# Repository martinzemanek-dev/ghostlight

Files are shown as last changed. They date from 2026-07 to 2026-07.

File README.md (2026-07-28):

# Ghostlight
Small board under a see-through miniature, to light it up. The board is powered by a battery and the light is programmable.
## Power supply
Circuit is expected to be build for 3V
### Battery
CR2032 for start. It needs holder at the bottom [BAT-HLD-001](https://cz.mouser.com/ProductDetail/712-BAT-HLD-001)
### Miscelenious
[MCP1700T-3302E/TT](https://cz.mouser.com/ProductDetail/Microchip-Technology/MCP1700T-3302E-TTVAO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)
[1kF](https://cz.mouser.com/ProductDetail/TAIYO-YUDEN/MBASG168AB7105KTNA01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)
[100nF](https://cz.mouser.com/ProductDetail/TAIYO-YUDEN/MLASU105SB7104KFNB25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)
[10uF](https://cz.mouser.com/ProductDetail/Murata-Electronics/GRM155C80G106ME18D?qs=doiCPypUmgHaqNm%2FsBDkxw%3D%3D)
[4.7 kilo ohm](https://www.gme.cz/v/1496357/yageo-r0603-4k7-01w-5-smd-rezistor)
## microcontroler
[STM32C011J4M6](https://cz.mouser.com/ProductDetail/511-STM32C011J4M6) (SO8 package) or [STM32C011J6M6](https://cz.mouser.com/cs/ProductDetail/511-STM32G030J6M6).

## LED
### LED control
[LP5817](https://cz.mouser.com/new/texas-instruments/ti-lp5817-3-channel-rgb-led-driver/) seems to be a good way to do it.
It will connect to u-controler to microcontroler. Communicates on I2C. Needs 100nF between Vcc and GND.
### LED component
While being small enough the [SB0606WC02-RGB](https://cz.mouser.com/ProductDetail/VCC/SB0606WC02-RGB?qs=rQFj71Wb1eX6WH%252BB20VtTw%3D%3D). Seems to be small and powered by 3V.

## Accelerometer
[LIS3DHTR](https://cz.mouser.com/ProductDetail/511-LIS3DHTR) seems to be a grat opinion. Its povered by up to 3.6V so the LDO should supply sufficient and safe power. It also communicates over I2C alongside LP5817 and doesn't collide in address. It will take over last free pins for interrupts. It also provides three analog outpusts, which can substitute the pins on the programming Ring for debuginng.

## Program
### Programing 
The board is programmeable with [STLINK-V3](https://cz.mouser.com/ProductDetail/511-STLINK-V3MINIE) with connected battery or powersupply. The programming pins are connected to ring of pins (Adapter between ring, programmer and power supply is currently work in progress). 

Here are pin functions going clockwise from pin 1.
| Pin | Function |
| --- | --- |
| 1 | Vdd (Power detection) |
| 2 | ST_LINK_SWCLK |
| 3 | ST_LINK_SWDIO |
| 4 | Unused |
| 5 | Unused |
| 6 | RESET |
| 7 | V_BATT |
| 8 | GND |

Programmer connected this way allows programming using STM32CubeProgrammer.
V_BATT is a dirrect connection to + of the battery.
It is also possible to connect external 3.3V power supply here, but only, when battery is disconnected.

### Logic

Current program rotates thrue multiple modes.
Upon Startup the device shortly blinks red and than is switchis to first program, which is shifts over few colours as a lavalamp.

After start-up, the program also starts checking on accelerometer status. 
Program goes thrue two fases, so the color would not change on accident.
First the program checks, if the device is tilted 90 degrees using X and Y acceleration from the accelerometer.
Than it waits, till the board is fully flipped and than it changes color.
All measurements are triggered by change interrupt from the LI3DH.
When Program color change is noticed, the program cycles true colors in following order.

| Order | Color |
| --- | --- |
| 1. | Lavalamp (slowly shifting colors) |
| 2. | Red |
| 3. | Green |
| 4. | Blue |
| 5. | Magenta |
| 6. | Yellow |
| 7. | Cyan |
| 8. | While |
| 9. | Off |
| 10. | Color visualization of the accelerometer output |

When the program displays static color it waits for an interrupt, before even checking the accelerometer.

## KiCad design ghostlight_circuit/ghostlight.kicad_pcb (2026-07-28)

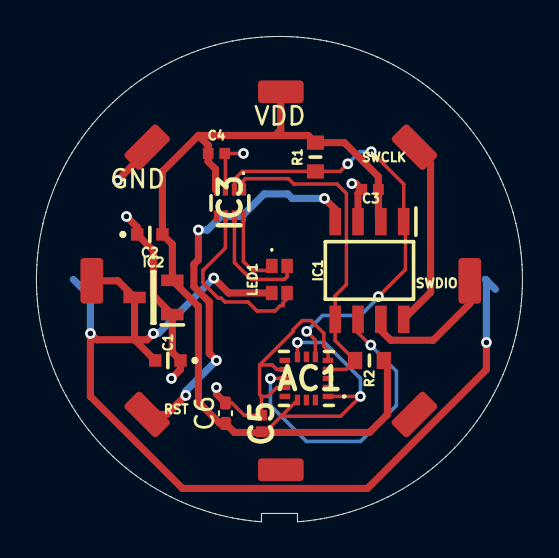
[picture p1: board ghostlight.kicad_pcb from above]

Board: 2 copper layers, 27.0 x 27.0 mm, 15 parts (1 on the bottom side), 11 nets.

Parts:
AC1: LIS3DHTR
BT1: BAT-HLD-001; BATHLD001mod
C1, C2: MBASG168AB7105KTNA01; MBASx168
C3, C4, C5: MLASU105SB7104KFNB25; CAPC1005X55N
C6: GRM155C80G106ME18D; C_0402_1005Metric_Pad0.74x0.62mm_HandSolder
IC1: STM32C011J4M6; SOIC127P600X175-8N
IC2: MCP1700T-3302E_TT; SOT95P237X112-3N
IC3: LP5817DRLR
J1: Conn_01x08; Ring_connector_22mm
LED1: SB0606WC02-RGB; SB0606WC02RGB
R1, R2: SR0603JR-074R7L; RESC1608X55N

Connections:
3.3V: AC1.1 (VDDIO), AC1.8 (CS), AC1.14 (VDD), C2.2, C3.1, C4.2, C5.1, C6.1, IC1.2 (VDD/VDDA), IC2.2 (VOUT), IC3.4 (VCC), J1.1, R1.1, R2.1
ACC_INT1: AC1.11 (INT1), IC1.6 (PA12[PA10])
GND: AC1.5 (GND_1), AC1.10 (RES), AC1.12 (GND_2), BT1.3 (-), C1.1, C2.1, C3.2, C4.1, C5.2, C6.2, IC1.3 (VSS/VSSA), IC2.1 (GND), IC3.3 (GND), J1.8
unnamed: IC3.8 (OUT0), LED1.1 (K_R)
unnamed: IC3.7 (OUT1), LED1.2 (K_G)
unnamed: IC3.6 (OUT2), LED1.3 (K_B)
SCK: AC1.4 (SCL/SPC), IC1.5 (PA11[PA9]/PA8), IC3.1 (SCL), R2.2
SDA: AC1.6 (SDA/SDI/SDO), IC1.1 (PB7/PC14-OSCX_IN), IC3.2 (SDA), R1.2
ST_LIKN_SWCLK: IC1.8 (PB6/PA14-BOOT0/PC15-OSCX_OUT), J1.2
ST_LINK_SWDIO: IC1.7 (PA13), J1.3
V_BAT: BT1.1 (+_1), BT1.2 (+_2), C1.2, IC2.3 (VIN), J1.7, LED1.4 (COM_A)

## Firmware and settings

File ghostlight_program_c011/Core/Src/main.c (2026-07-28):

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
/* Includes ------------------------------------------------------------------*/
#include "main.h"
#include "adc.h"
#include "dma.h"
#include "i2c.h"
#include "tim.h"
#include "gpio.h"

/* USER CODE BEGIN Includes */
#include "LP5817.h"
#include "LIS3DH.h"
/* USER CODE END Includes */


/* USER CODE BEGIN PV */
volatile int mode = 0;
volatile int measure = 1;
volatile int change_mod = 0;
/* USER CODE END PV */

void SystemClock_Config(void);
/* USER CODE BEGIN 0 */
void handleI2CErr(uint8_t error_code) {
	//HAL_GPIO_WritePin(LIVE_GPIO_Port, LIVE_Pin, RESET);
	// Check if any error occurred (Bit 0 is our 'Error Present' marker)
	if (error_code) {
		while (1) {
		}
	}
}

#define MAX_BRIGHT 100
#define SCALE(val) ((val * MAX_BRIGHT) / 255)

/**
 * @brief set color based on the hue(0-329)
 *
 * @param hue, number between 0 and 365, which chooses specific HUE
 */
void SetRainbowColor(uint16_t hue) {
	uint8_t r = 0, g = 0, b = 0;
	uint8_t region = hue / 60;
	uint8_t remainder = (hue % 60) * 255 / 60;

	uint8_t p = 0; // Matching 0% brightness base
	uint8_t q = 255 - remainder;
	uint8_t t = remainder;

	// Scale down from 255 to your maximum target brightness (e.g., max 150 to not blind you)

	switch (region) {
	case 0:
		r = 255;
		g = t;
		b = p;
		break;
	case 1:
		r = q;
		g = 255;
		b = p;
		break;
	case 2:
		r = p;
		g = 255;
		b = t;
		break;
	case 3:
		r = p;
		g = q;
		b = 255;
		break;
	case 4:
		r = t;
		g = p;
		b = 255;
		break;
	default:
		r = 255;
		g = p;
		b = q;
		break;
	}

	// Call your driver with the scaled relaxing colors
	LP5817_setColor(SCALE(r), SCALE(g), SCALE(b));
}

/**
 * @brief rutine, which cycles thru hues (0-359) in 30 ms intervals
 */
void rainbowRutine() {
	static uint16_t hue = 0;
	SetRainbowColor(hue);

	hue++;
	if (hue >= 360) {
		hue = 0;
	}

	HAL_Delay(30);
}

/**
 * @brief rutine, which sets colour based on accelerometer output
 */
void displayLISOutputRutine() {
	static int16_t accel_x = 0;
	static int16_t accel_y = 0;
	static int16_t accel_z = 0;
	//Update colour based on accelerometer output
	LIS3DH_getAxes(&accel_x, &accel_y, &accel_z);
	// 2. Convert to absolute values (so upside-down or backwards movement still creates light)
	// We divide by 4 to map ~1000 (1G of gravity) down to ~250 (perfect for an 8-bit LED channel)
	int16_t r_val = (accel_x >= 0 ? accel_x : (-accel_x)) / 64;
	int16_t g_val = (accel_y >= 0 ? accel_y : (-accel_y)) / 64;
	int16_t b_val = (accel_z >= 0 ? accel_z : (-accel_z)) / 64;

	// 3. Constrain the values between 0 and 255 just to protect against high-acceleration spikes
	if (r_val > 255)
		r_val = 255;
	if (g_val > 255)
		g_val = 255;
	if (b_val > 255)
		b_val = 255;
	if (r_val < b_val && r_val < g_val) {
		r_val = 0;
	} else if (b_val < g_val) {
		b_val = 0;
	} else {
		g_val = 0;
	}
	LP5817_setColor(SCALE((uint8_t )r_val), SCALE((uint8_t )g_val),
			SCALE((uint8_t )b_val));
	// Adjust this delay to speed up or slow down the transition.
	// 30ms gives a beautifully smooth, tranquil fade.
	HAL_Delay(30);
}

void updateMode() {
	if (measure) {
		int16_t x = 0, y = 0, z = 0;
		LIS3DH_getAxes(&x, &y, &z);

		if (change_mod) {
			//check z
			if (z < -10000) {
				mode++;
				mode %= 10;
			}
			change_mod = 0;
		} else {
			int32_t x_scaled = x / 64;
			int32_t y_scaled = y / 64;
			if ((x_scaled * x_scaled) + (y_scaled * y_scaled) > 50000) {
				change_mod = 1;
			}
		}
		measure = 0;
	}
}
/* USER CODE END 0 */

/**
  * @brief  The application entry point.
  * @retval int
  */
int main(void)
{

  /* MCU Configuration--------------------------------------------------------*/

  /* Reset of all peripherals, Initializes the Flash interface and the Systick. */
  HAL_Init();

  /* Configure the system clock */
  SystemClock_Config();

  /* Initialize all configured peripherals */
  MX_GPIO_Init();
  MX_DMA_Init();
  MX_I2C1_Init();
  MX_ADC1_Init();
  MX_TIM14_Init();
  /* USER CODE BEGIN 2 */

	uint8_t i2c_err = LP5817_init();
	HAL_Delay(1);
	handleI2CErr(i2c_err);

	LP5817_setColor(255, 0, 0);

	i2c_err = LIS3DH_init();
	HAL_Delay(1);
	handleI2CErr(i2c_err);

	HAL_Delay(500);

  /* USER CODE END 2 */

  /* Infinite loop */
  /* USER CODE BEGIN WHILE */
	while (1) {
    /* USER CODE END WHILE */

    /* USER CODE BEGIN 3 */
		uint8_t clear_buffer = 0;
		LIS3DH_read_reg(0x31, &clear_buffer, 1);

		switch (mode) {
		case 0:
			rainbowRutine();
			break;
		case 1:
			//red
			LP5817_setColor(SCALE(255), 0, 0);
			__WFI();
			break;
		case 2:
			//green
			LP5817_setColor(0, SCALE(255), 0);
			__WFI();
			break;
		case 3:
			//blue
			LP5817_setColor(0, 0, SCALE(255));
			__WFI();
			break;
		case 4:
			//magenta
			LP5817_setColor(SCALE(255), 0, SCALE(255));
			__WFI();
			break;
		case 5:
			//yellow
			LP5817_setColor(SCALE(255), SCALE(255), 0);
			__WFI();
			break;
		case 6:
			//cyan?
			LP5817_setColor(0, SCALE(255), SCALE(255));
			__WFI();
			break;
		case 7:
			//white
			LP5817_setColor(255, 255, 255);
			__WFI();
			break;
		case 8:
			//off
			LP5817_setColor(0, 0, 0);
			__WFI();
			break;
		case 9:
			displayLISOutputRutine();
		};

	}
  /* USER CODE END 3 */
}

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
/* USER CODE BEGIN 4 */
void HAL_GPIO_EXTI_Rising_Callback(uint16_t GPIO_Pin) {
	if (GPIO_Pin == LIS3_INT1_Pin) {
		measure = 1;
	}
}
/* USER CODE END 4 */
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


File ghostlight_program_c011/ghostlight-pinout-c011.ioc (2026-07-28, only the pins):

Mcu.UserName=STM32C011J4Mx
PA13.Signal=DEBUG_SWDIO
PA14-BOOT0.Signal=DEBUG_SWCLK

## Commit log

2026-03-25 Create empty KiCad project
    [ghostlight.kicad_pcb, ghostlight.kicad_sch]
2026-04-04 added first scheme for the board
    [ghostlight.kicad_sch]
2026-04-07 Add 2 missing cheme pages
    [led.kicad_sch, mcu.kicad_sch]
2026-04-07 Add component shapes, to cheme
    [ghostlight.kicad_pcb]
2026-04-07 added first board draft
    [ghostlight.kicad_pcb]
2026-04-07 added custom ring for programming
    [ghostlight.kicad_pcb, programming_connector.kicad_sch]
2026-04-07 optimalized the PCB
    [ghostlight.kicad_pcb]
2026-04-09 Create folder for outputs
    [ghostlight.kicad_pcb]
2026-04-19 Implement program for LED + cleanup
2026-04-21 change in schematic
    [ghostlight.kicad_pcb, mcu.kicad_sch, programming_connector.kicad_sch]
2026-04-22 Add Test Points
    [ghostlight.kicad_pcb, led.kicad_sch]
2026-05-05 Add new battery holder
    [ghostlight.kicad_pcb, ghostlight.kicad_sch]
2026-05-05 Board revision 2 - better spacing, test points and connect pins to ring
    [ghostlight-B_Cu.gbr, ghostlight-B_Mask.gbr, ghostlight-B_Paste.gbr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]
2026-05-05 Demo, which lights up the LED
2026-05-07 rename folders
    [ghostlight-B_Cu.gbr, ghostlight-B_Mask.gbr, ghostlight-B_Paste.gbr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]
2026-05-13 rerouted the board
    [ghostlight.kicad_pcb, mcu.kicad_sch, programming_connector.kicad_sch]
2026-05-14 Added accelerometer to the schematic
    [accelorometer.kicad_sch]
2026-05-15 update pcb
    rerout and connect accelerometer
    better re-route
    [accelorometer.kicad_sch, ghostlight.kicad_pcb, ghostlight.kicad_sch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]
2026-05-15 rebase scheme repair
    [ghostlight.kicad_pcb]
2026-06-03 TMP: added output files
    [ghostlight-B_Cu.gbr, ghostlight-B_Mask.gbr, ghostlight-B_Paste.gbr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]
2026-07-05 created pinout file for stm32g030
2026-07-05 generated stm32g030 project
2026-07-06 Working without accelerometer
2026-07-28 refactor c011 the program for the new board
2026-07-28 Revise regulator and microcontroller details in README
    Updated regulator section to include STM32C011J6M6 and clarified capacitor and resistor requirements.

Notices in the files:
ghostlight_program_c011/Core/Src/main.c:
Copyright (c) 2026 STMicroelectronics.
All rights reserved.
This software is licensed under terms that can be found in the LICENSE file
